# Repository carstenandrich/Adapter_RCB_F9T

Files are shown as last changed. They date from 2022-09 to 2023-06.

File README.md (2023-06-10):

# u-blox RCB-F9T Adapter PCB w/ USB and SMA

Stackable adapter PCB for u-blox [RCB-F9T timing board](https://www.u-blox.com/en/product/rcb-f9t-timing-board) with the following features:

  * USB-to-UART converter (SiLabs CP2102)
  * fully USB-powered (option to supply RCB-F9T from low noise voltage source)
  * SMA connectors for TP1 and TP2 pins of RCB-F9T
  * SMA can drive 50 Ohm loads via buffer opamp (TI BUF602)

This repository contains KiCad EDA files of the PCB design and [JLCPCB fabrication files](./fabrication).

## Renderings of Adapter PCB with/without RCB-F9T

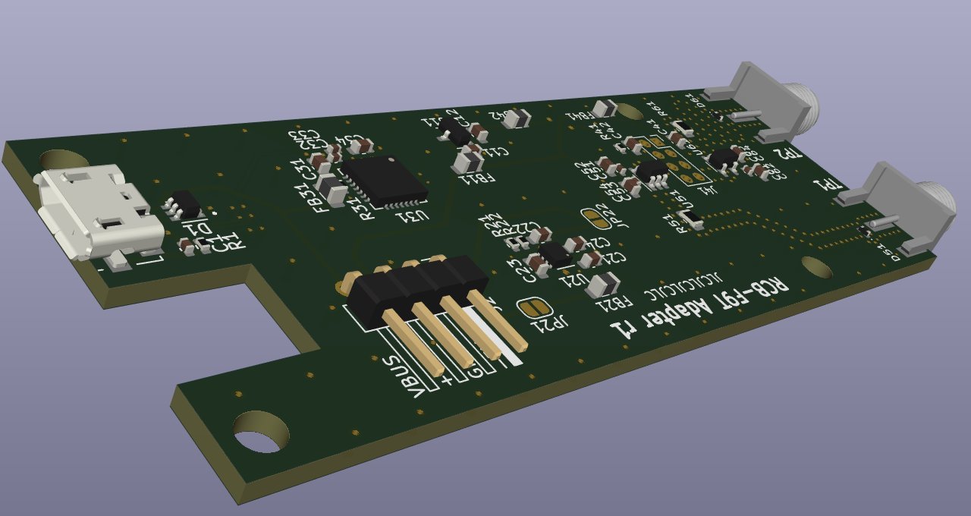
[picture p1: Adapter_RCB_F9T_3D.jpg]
Rendering of adapter PCB without RCB-F9T

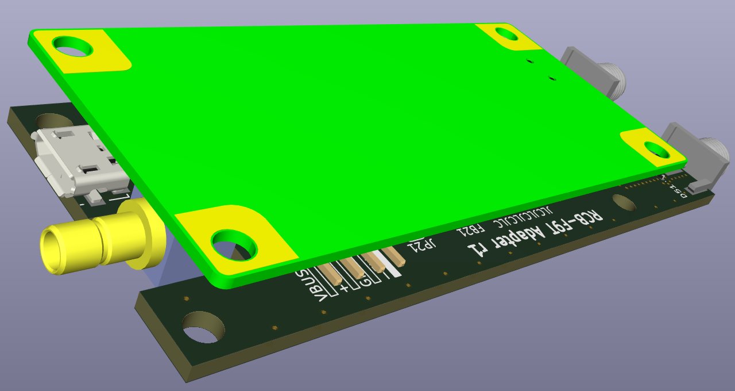
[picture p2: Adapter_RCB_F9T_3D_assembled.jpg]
Rendering of adapter PCB with RCB-F9T


# Revisions

## Revision 1

Initial revision including JLCPCB fabrication files.

**Known Issues**:

  * RCB-F9T NRST pin is incorrectly treated as RST (pulled down via R41)
  * FB41 is too close to mounting hole

Board is fully operational after desoldering R41.

### Image of Adapter PCB with RCB-F9T

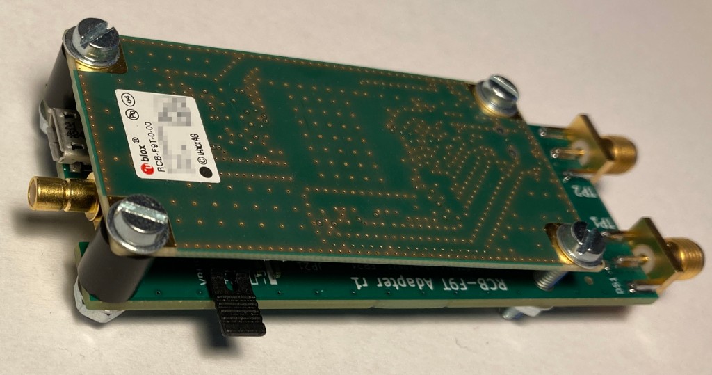
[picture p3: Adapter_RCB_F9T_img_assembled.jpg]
Image of adapter PCB rev. 1 with RCB-F9T


## Revision 2

Above issues fixed in EDA files (**not** fabrication files), but design was neither produced nor verified.

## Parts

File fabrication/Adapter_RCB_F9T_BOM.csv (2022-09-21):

Comment | Designator | Footprint | LCSC Part #
100n Unpolarized capacitor, small symbol | C1,C32,C33,C51,C53,C61,C63 | C_0402_1005Metric | C307331
1u Unpolarized capacitor, small symbol | C11,C12,C23,C31,C34,C41,C42 | C_0603_1608Metric | C15849
4u7 Unpolarized capacitor, small symbol | C21,C24,C52,C54,C62,C64 | C_0603_1608Metric | C96446
2u2 Unpolarized capacitor, small symbol | C22 | C_0603_1608Metric | C19666
SMF05CT1G TVS Diode Array, 5.5V Standoff, 5 Channels, SC-70-6 package | D1 | SOT-363_SC-70-6 | C15879
D_TVS Bidirectional transient-voltage-suppression diode | D51,D61 | D_0402_1005Metric | C316049
600R Ferrite bead, small symbol | FB11,FB21,FB31 | L_0805_2012Metric | C1017
100R Ferrite bead, small symbol | FB41,FB42 | L_0805_2012Metric | C1015
USB_B_Micro USB Micro Type B connector | J1 | USB_Micro-B_Molex_47346-0001 | C132560
Conn_01x04 Generic connector, single row, 01x04, script generated (kicad-library-utils/schlib/autogen/connector/) | J2 | PinHeader_1x04_P2.54mm_Horizontal
RCB_F9T | J41 | RCB_F9T
Conn_Coaxial coaxial connector (BNC, SMA, SMB, SMC, Cinch/RCA, LEMO, ...) | J51,J61 | SMA_Rosenberger_32K145-400L5_EdgeMount_Horizontal
SolderJumper_2_Bridged Solder Jumper, 2-pole, closed/bridged | JP21,JP22 | SolderJumper-2_P1.3mm_Bridged_RoundedPad1.0x1.5mm
1M Resistor, small symbol | R1,R21 | R_0402_1005Metric | C26083
330k Resistor, small symbol | R22 | R_0402_1005Metric | C25778
4k7 Resistor, small symbol | R31,R41 | R_0402_1005Metric | C25900
49.9 Resistor, small symbol | R51,R61 | R_0805_2012Metric | C17720
XC6206PxxxMR Positive 60-250mA Low Dropout Regulator, Fixed Output, SOT-23 | U11 | SOT-23 | C5446
LM27761 low-noise regulated switched-capacitor voltage inverter with 2.7V-5.5V input to -1.5 to -5V Output Voltage, WSON-8 | U21 | WSON-8-1EP_2x2mm_P0.5mm_EP0.9x1.6mm | C129351
CP2102-GMR-xQFN28 USB to UART master bridge, QFN-28 | U31 | QFN-28-1EP_5x5mm_P0.5mm_EP3.35x3.35mm | C6568
BUF602xDBV High-Speed, 1000 MHz, Closed-Loop Buffer, SOT23-5 | U51,U61 | SOT-23-5

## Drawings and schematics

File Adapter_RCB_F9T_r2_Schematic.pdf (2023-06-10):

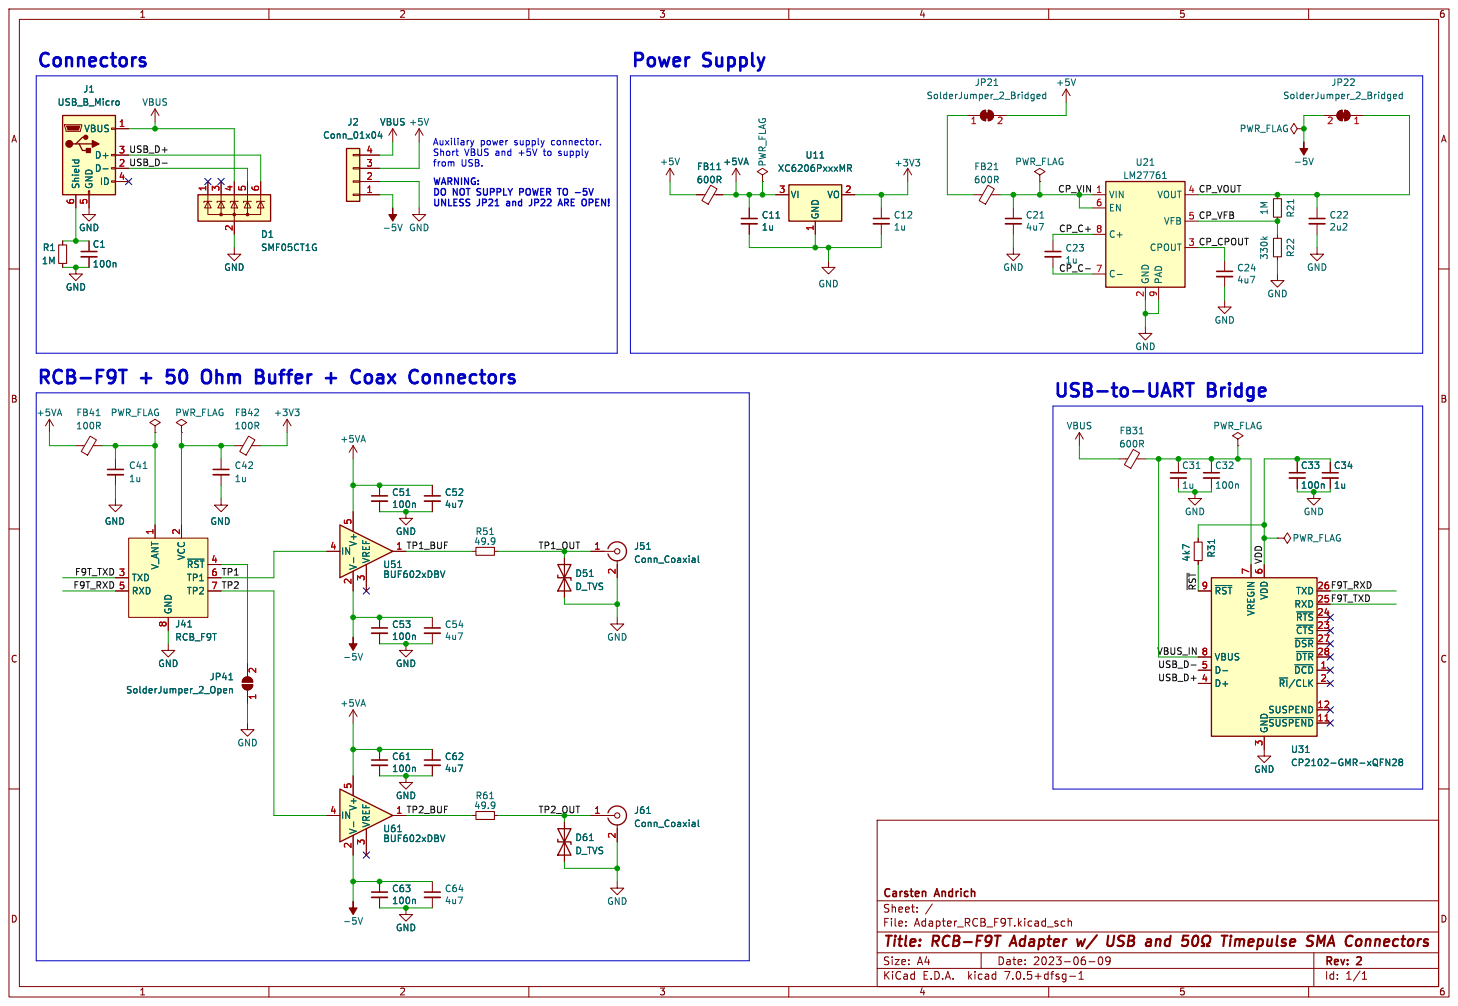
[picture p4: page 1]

2 CPOUT 3 VOUT 4 VFB 5 EN 6 C- 7 C+ 8 PAD

7 VBUS 8 ~{RST} 9 U31 CP2102-GMR-xQFN28 GND

File: Adapter_RCB_F9T.kicad_sch Sheet: / Carsten Andrich GND GND

Id: 1/1 Title: RCB-F9T Adapter w/ USB and þÿ50©Timepulse SMA Connectors

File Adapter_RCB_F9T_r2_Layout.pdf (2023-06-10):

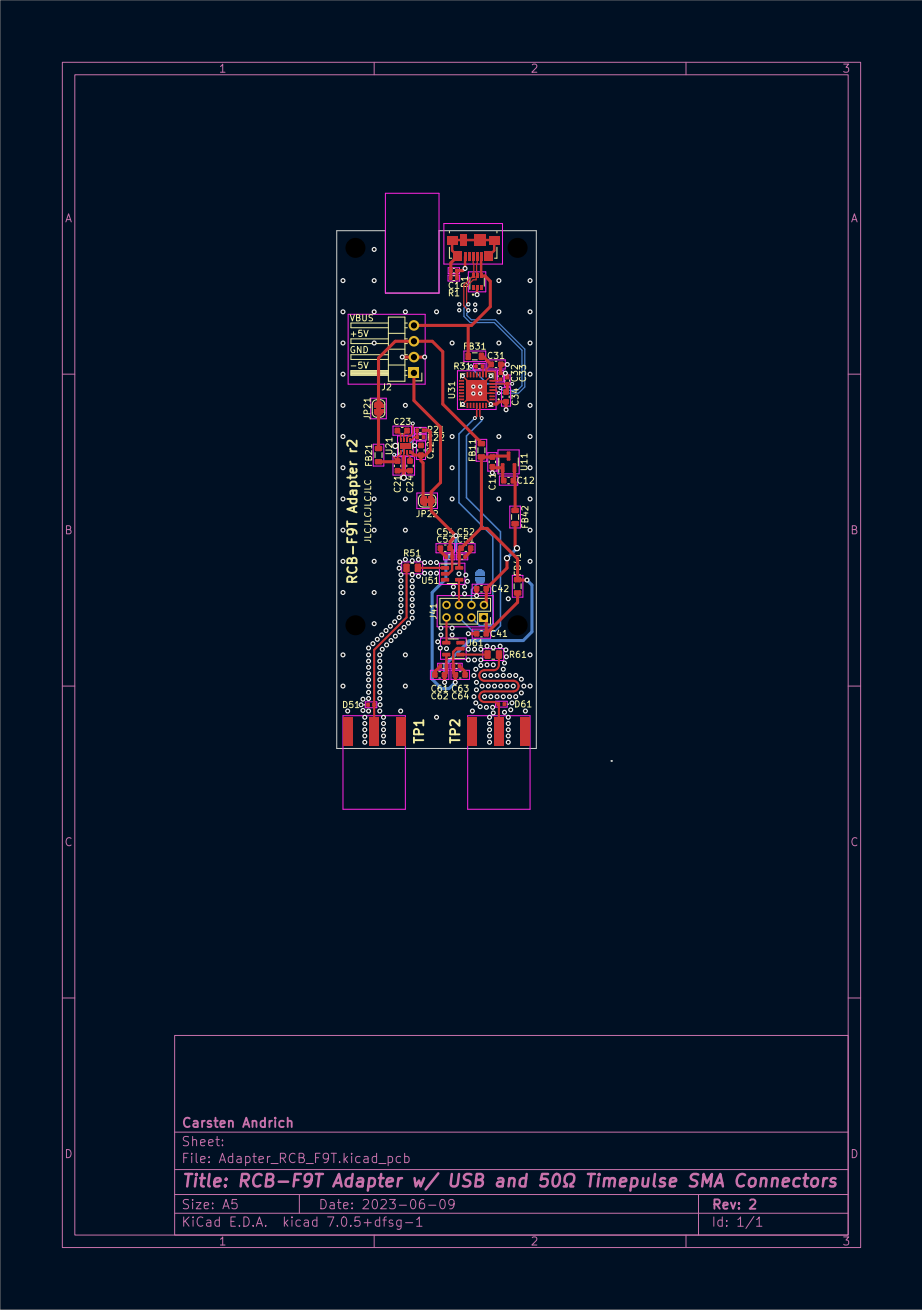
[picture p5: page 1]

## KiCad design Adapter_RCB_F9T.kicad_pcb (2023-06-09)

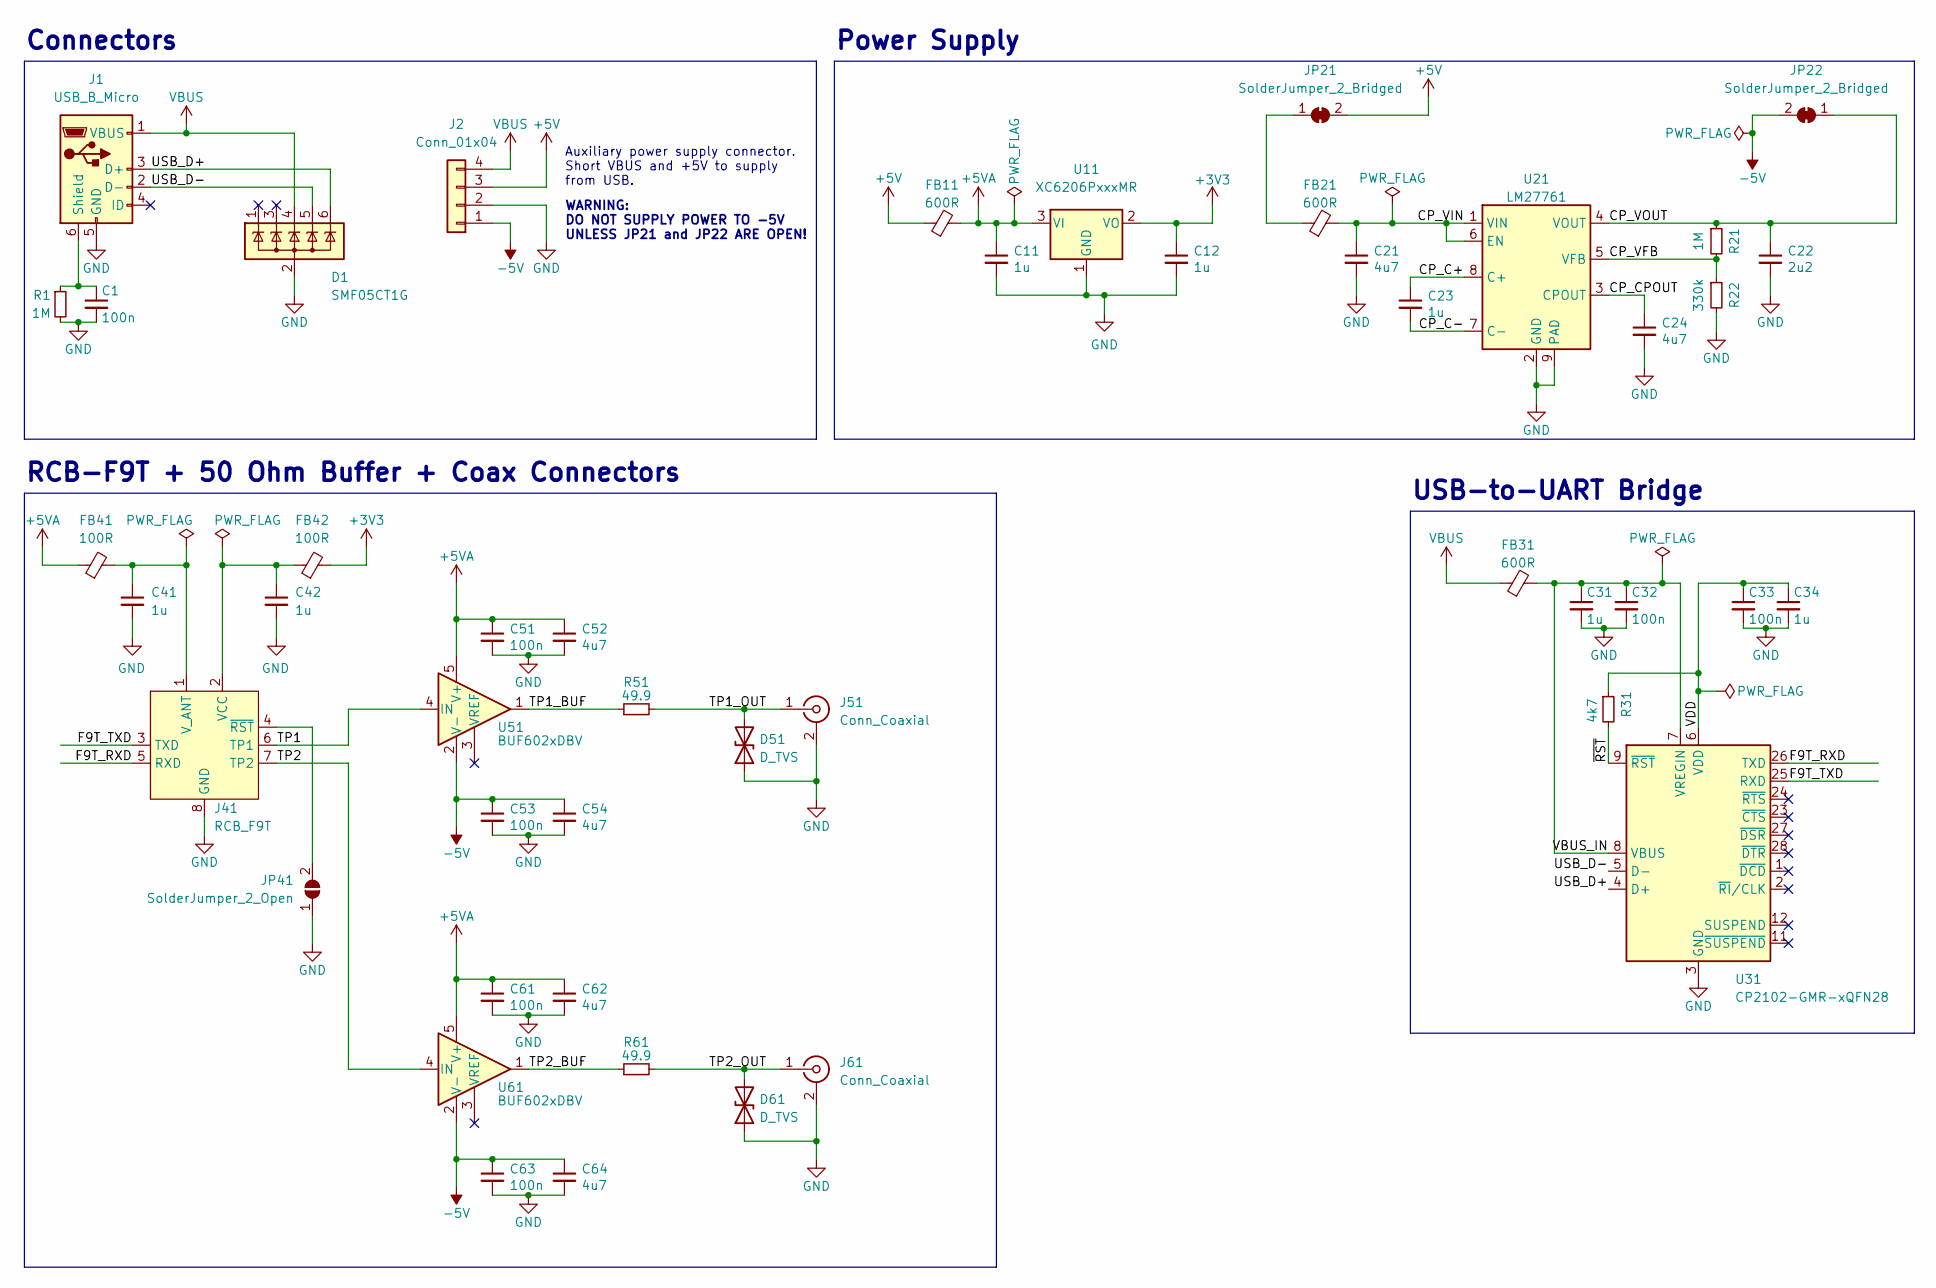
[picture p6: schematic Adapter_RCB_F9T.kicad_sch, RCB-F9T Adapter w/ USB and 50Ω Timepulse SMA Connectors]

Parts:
C1, C32, C33, C51, C53, C61, C63: 100n; C_0402_1005Metric; MPN CL05B104KB54PNC; LCSC C307331
C11, C12, C23, C31, C34, C41, C42: 1u; C_0603_1608Metric; MPN CL10A105KB8NNNC; LCSC C15849
C21, C24, C52, C54, C62, C64: 4u7; C_0603_1608Metric; MPN CL10A106MA8NRNC; LCSC C96446
C22: 2u2; C_0603_1608Metric; MPN CL10A475KO8NNNC; LCSC C19666
D1: SMF05CT1G; SOT-363_SC-70-6; LCSC C15879
D51, D61: D_TVS; D_0402_1005Metric; MPN 0402ESDA-05N; LCSC C316049
FB11, FB21, FB31: 600R; L_0805_2012Metric; LCSC C1017
FB41, FB42: 100R; L_0805_2012Metric; LCSC C1015
J1: USB_B_Micro; USB_Micro-B_Molex_47346-0001; LCSC C132560
J2: Conn_01x04; PinHeader_1x04_P2.54mm_Horizontal
J41: RCB_F9T
J51, J61: Conn_Coaxial; SMA_Rosenberger_32K145-400L5_EdgeMount_Horizontal; MPN 32K145-400L5
JP21, JP22: SolderJumper_2_Bridged; SolderJumper-2_P1.3mm_Bridged_RoundedPad1.0x1.5mm
JP41: SolderJumper_2_Open; SolderJumper-2_P1.3mm_Open_RoundedPad1.0x1.5mm
R1, R21: 1M; R_0402_1005Metric; MPN 0402WGF1004TCE; LCSC C26083
R22: 330k; R_0402_1005Metric; MPN 0402WGF3303TCE; LCSC C25778
R31: 4k7; R_0402_1005Metric; LCSC C25900
R51, R61: 49.9; R_0805_2012Metric; MPN R 49.9R 125mW 0805; LCSC C17720
U11: XC6206PxxxMR; SOT-23; LCSC C5446
U21: LM27761; WSON-8-1EP_2x2mm_P0.5mm_EP0.9x1.6mm; LCSC C129351
U31: CP2102-GMR-xQFN28; QFN-28-1EP_5x5mm_P0.5mm_EP3.35x3.35mm; LCSC C6568
U51, U61: BUF602xDBV; SOT-23-5; MPN BUF602xDBV

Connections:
+3V3: C12.1, FB42.2, U11.2 (VO)
+5V: FB11.1, J2.3, JP21.2 (B)
+5VA: C11.1, C51.1, C52.1, C61.1, C62.1, FB11.2, FB41.1, U11.3 (VI), U51.5 (V+), U61.5 (V+)
-5V: C53.1, C54.1, C63.1, C64.1, J2.1, JP22.2 (B), U51.2 (V-), U61.2 (V-)
/CP_C+: C23.1, U21.8 (C+)
/CP_C-: C23.2, U21.7 (C-)
/CP_CPOUT: C24.1, U21.3 (CPOUT)
/CP_VFB: R21.2, R22.1, U21.5 (VFB)
/CP_VIN: C21.1, FB21.2, U21.1 (VIN), U21.6 (EN)
/CP_VOUT: C22.1, JP22.1 (A), R21.1, U21.4 (VOUT)
/F9T_RXD: J41.5 (RXD), U31.26 (TXD)
/F9T_TXD: J41.3 (TXD), U31.25 (RXD)
/TP1: J41.6 (TP1), U51.4 (IN)
/TP1_BUF: R51.1, U51.1
/TP1_OUT: D51.2 (A2), J51.1 (In), R51.2
/TP2: J41.7 (TP2), U61.4 (IN)
/TP2_BUF: R61.1, U61.1
/TP2_OUT: D61.2 (A2), J61.1 (In), R61.2
/USB_D+: D1.6 (K), J1.3 (D+), U31.4 (D+)
/USB_D-: D1.5 (K), J1.2 (D-), U31.5 (D-)
/VBUS_IN: C31.1, C32.1, FB31.2, U31.7 (VREGIN), U31.8 (VBUS)
/VDD: C33.1, C34.1, R31.1, U31.6 (VDD)
/~RST: R31.2, U31.9 (~RST)
GND: C1.2, C11.2, C12.2, C21.2, C22.2, C24.2, C31.2, C32.2, C33.2, C34.2, C41.2, C42.2, C51.2, C52.2, C53.2, C54.2, C61.2, C62.2, C63.2, C64.2, D1.2 (A), D51.1 (A1), D61.1 (A1), J1.5 (GND), J2.2, J41.8 (GND), J51.2 (Ext), J61.2 (Ext), JP41.1 (A), R1.2, R22.2, U11.1 (GND), U21.2 (GND), U21.9 (PAD), U31.3 (GND), U31.29 (GND)
unnamed: C1.1, J1.6 (Shield), R1.1
unnamed: C42.1, FB42.1, J41.2 (VCC)
unnamed: C41.1, FB41.2, J41.1 (V_ANT)
unnamed: J41.4 (~RST), JP41.2 (B)
unnamed: FB21.1, JP21.1 (A)
VBUS: D1.4 (K), FB31.1, J1.1 (VBUS), J2.4

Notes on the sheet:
Auxiliary power supply connector. Short VBUS and +5V to supply from USB.
WARNING: DO NOT SUPPLY POWER TO -5V UNLESS JP21 and JP22 ARE OPEN!
Power Supply
Connectors
RCB-F9T + 50 Ohm Buffer + Coax Connectors
USB-to-UART Bridge

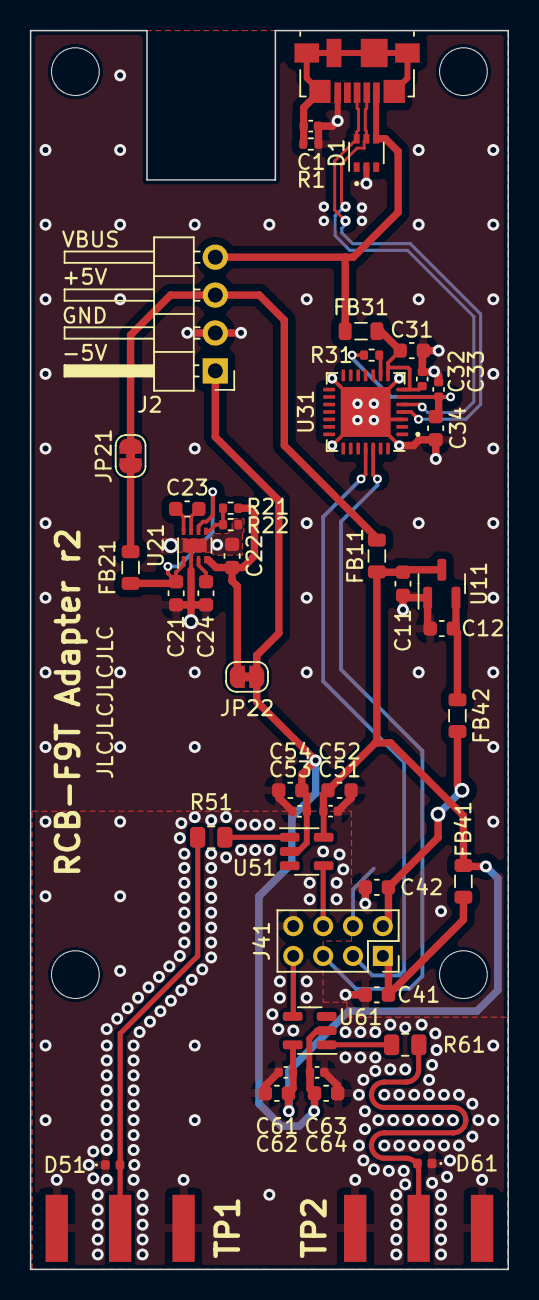
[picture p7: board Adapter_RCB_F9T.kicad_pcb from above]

Board: 4 copper layers, 32.0 x 83.0 mm, 48 parts (1 on the bottom side), 30 nets.

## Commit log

2022-09-21 add revision 1 design and fabrication files
    [Adapter_RCB_F9T-B_Cu.gbr, Adapter_RCB_F9T-B_Mask.gbr, Adapter_RCB_F9T-B_Paste.gbr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]
2023-06-09 fix RCB-F9T NRST issue and move FB41 further away from mounting hole
    [Adapter_RCB_F9T.kicad_pcb, Adapter_RCB_F9T.kicad_sch]
